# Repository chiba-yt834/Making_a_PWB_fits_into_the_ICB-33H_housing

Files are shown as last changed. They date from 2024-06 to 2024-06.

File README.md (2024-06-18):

## タイトル  
市民ラジオトランシーバー  ICB-33Hの筐体に入る基板  

## はじめに
ICB-33Hの筐体に入る基板を設計したので、情報を公開します。
ICB-33Hは1980年代から1990年代にかけて販売されていたソニー製の市民ラジオのトランシーバーです。  
  
中身を入れ替えることで、新たな市民ラジオのトランシーバーを製作したり、周波数の近い28MHz帯の
アマチュア無線のトランシーバーを製作することができます。
  
本書では設計した基板の外形寸法、スイッチやボリュームなど筐体にとりつく部品の配置、部品の高さ制限の情報などを示します。

## 外形寸法
基板の外形寸法を以下に示します。

[outline_drawing.pdf](./pdf/outline_drawing.pdf)  
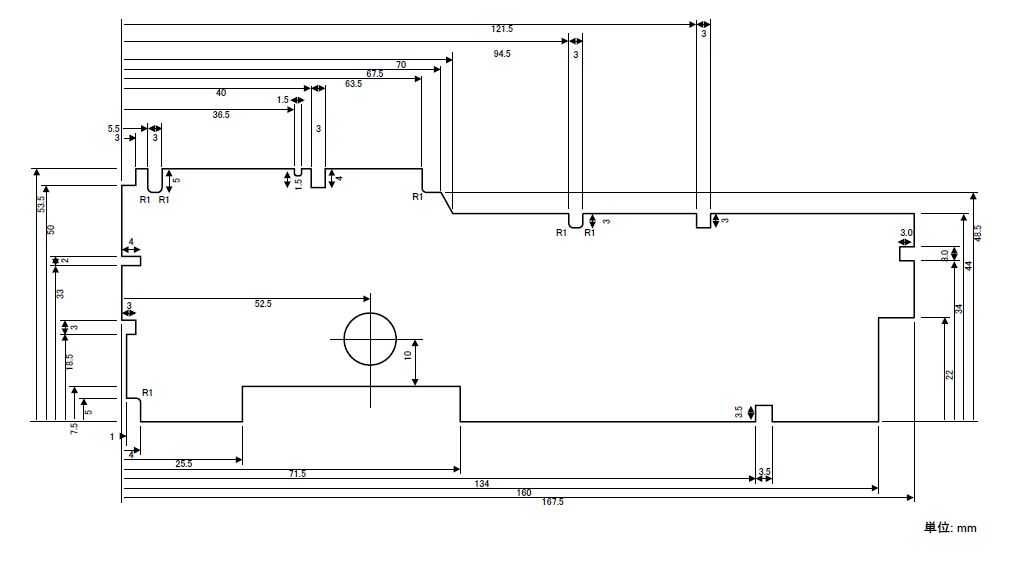
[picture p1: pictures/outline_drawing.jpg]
外形寸法図
  

## ドリル・部品配置
ドリルおよび部品配置の情報を以下に示します。
取り付け穴は全部で4つです。
電池接続パッドは半田面に配置します。それ以外の部品は全て部品面に配置します。

[drill_and_components_layout.pdf](./pdf/drill_and_components_layout.pdf)  
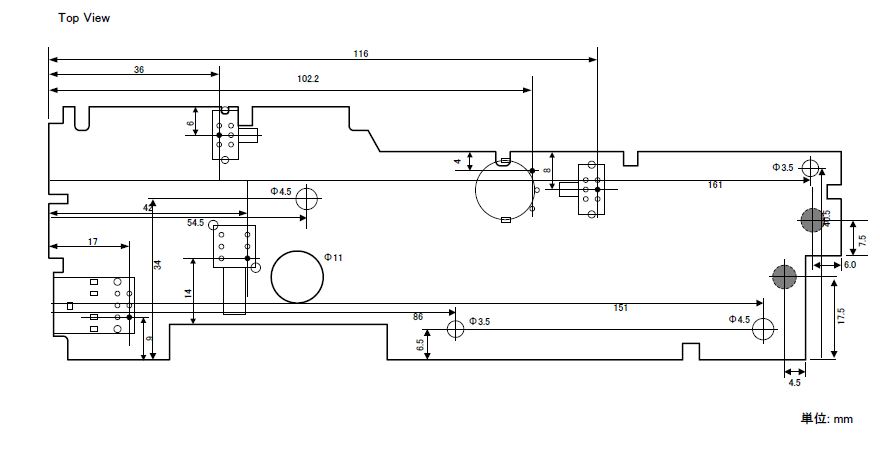
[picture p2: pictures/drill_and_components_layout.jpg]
ドリル・部品配置
  

## 高さ制限
部品面、半田面の高さ制限の情報を以下に示します。
スイッチやボリュームと連動する機構部品や、スピーカーなどと干渉するため、部品の高さ制限や配置禁止領域があります。

* 部品面  
[height_limit(component_side).pdf](./pdf/height_limit(component_side).pdf)  
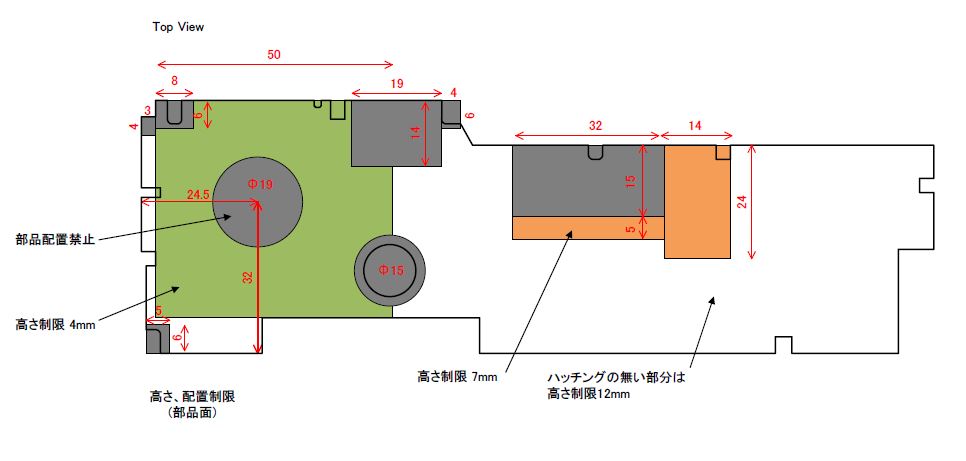
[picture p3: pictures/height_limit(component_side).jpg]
高さ制限_部品面
  
* 半田面  
[height_limit(solder_side).pdf](./pdf/height_limit(solder_side).pdf)  
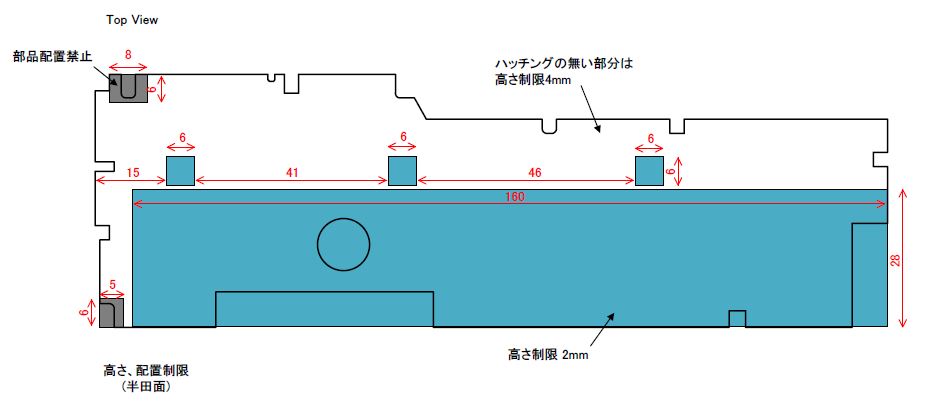
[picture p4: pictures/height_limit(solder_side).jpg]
高さ制限_半田面
  

## 部品
部品取り付け穴の情報を示します。
マイク・イヤホンジャックの部品は位置決め用の樹脂製のボスがありますが、下図には記載していません。ボスを切除してしまうか、
基板に穴を追加する必要があります。

[components.pdf](./pdf/components.pdf)  
* チャネル選択スイッチ  
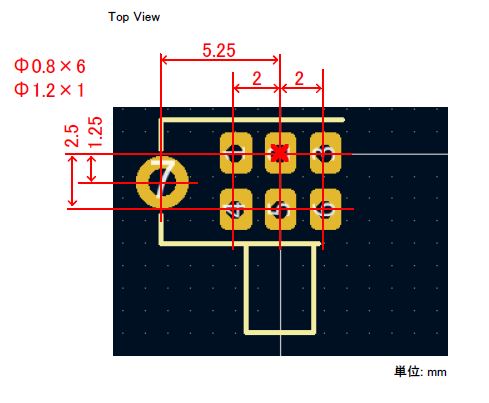
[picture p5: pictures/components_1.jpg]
  
* 電源スイッチ  
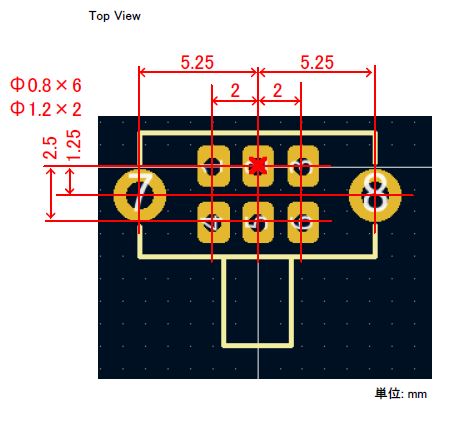
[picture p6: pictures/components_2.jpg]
  
* PTTスイッチ  
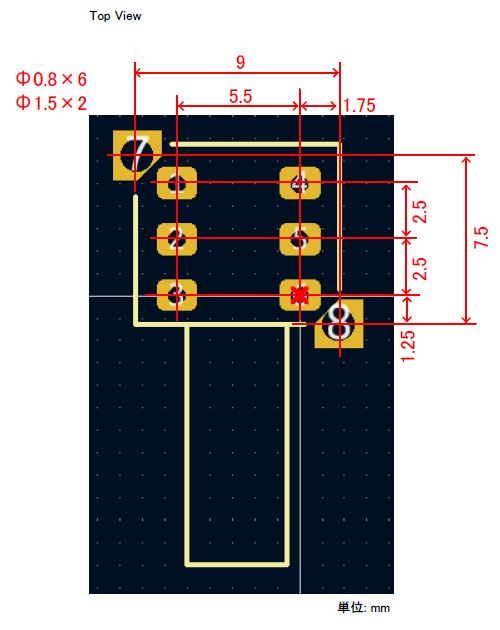
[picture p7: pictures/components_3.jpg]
  
* 音量調節ボリューム  
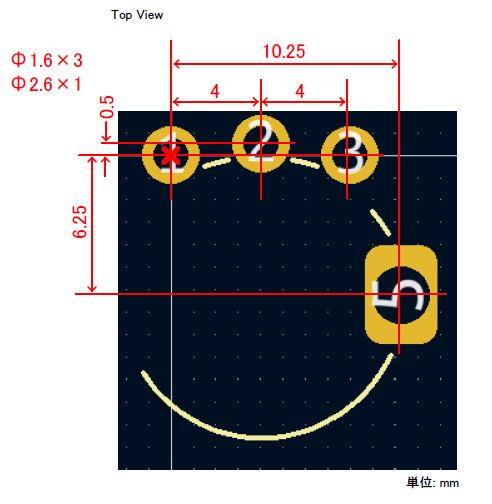
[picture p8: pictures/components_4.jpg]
  
* イヤホン・マイクコネクタ  
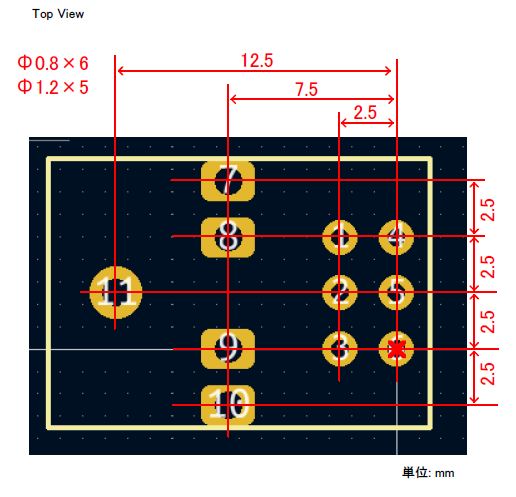
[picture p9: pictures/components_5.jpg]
  
* 電池接続パッド  
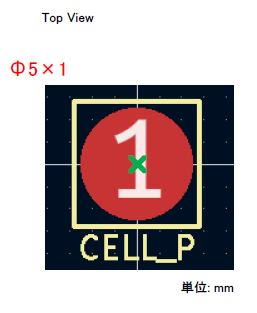
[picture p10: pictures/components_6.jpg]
  

## 実装
基板に部品を実装した様子を示します。
ボリュームの取り付け位置がシビアです。ボリュームの取り付け穴は大きめに設計してあり、遊びを設けてあります。
筐体に基板を組付けてボリュームの取付位置を決めてから、残りの部品を取り付けるとうまくいきます。

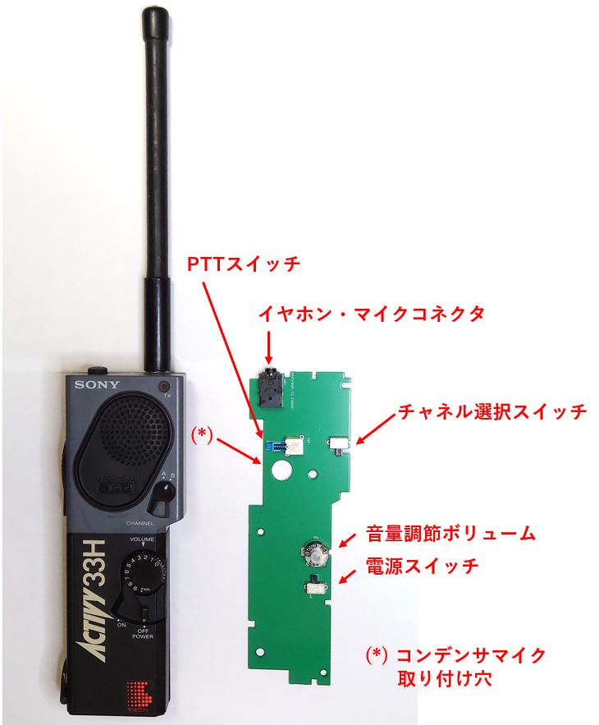
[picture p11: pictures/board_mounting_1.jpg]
実装_部品面
  
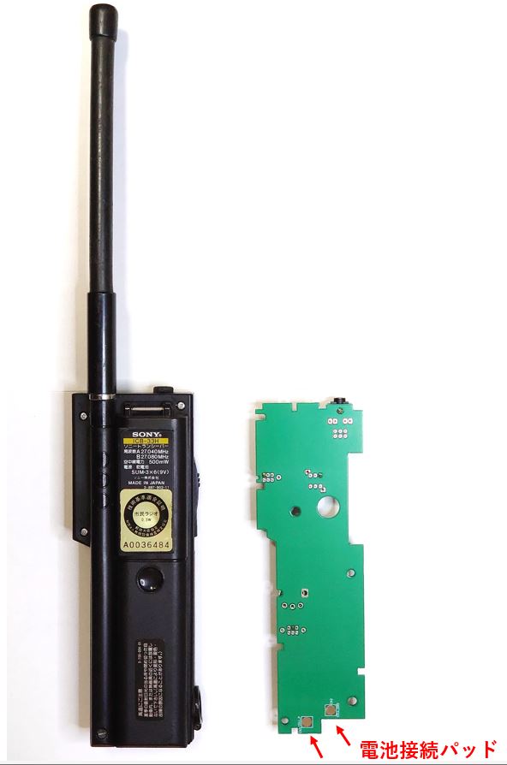
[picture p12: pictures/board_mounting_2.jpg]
実装_半田面
  

## その他 設計情報
上記で示した基板のガーバーデータ、KiCAD データを示します。KiCADはバージョン6.0です。

[gerbers](./gerbers)  
[KiCAD](./KiCAD)  

## 作例
この基板を用いて市民ラジオのトランシーバーを製作し、技適を受けることができました(120mW, 2ch機)。
試験的な交信はできています。
ホイップアンテナは筐体上部にねじ止めされていますが、この部分と基板を電気的にどのように接続するかが難しいところです。

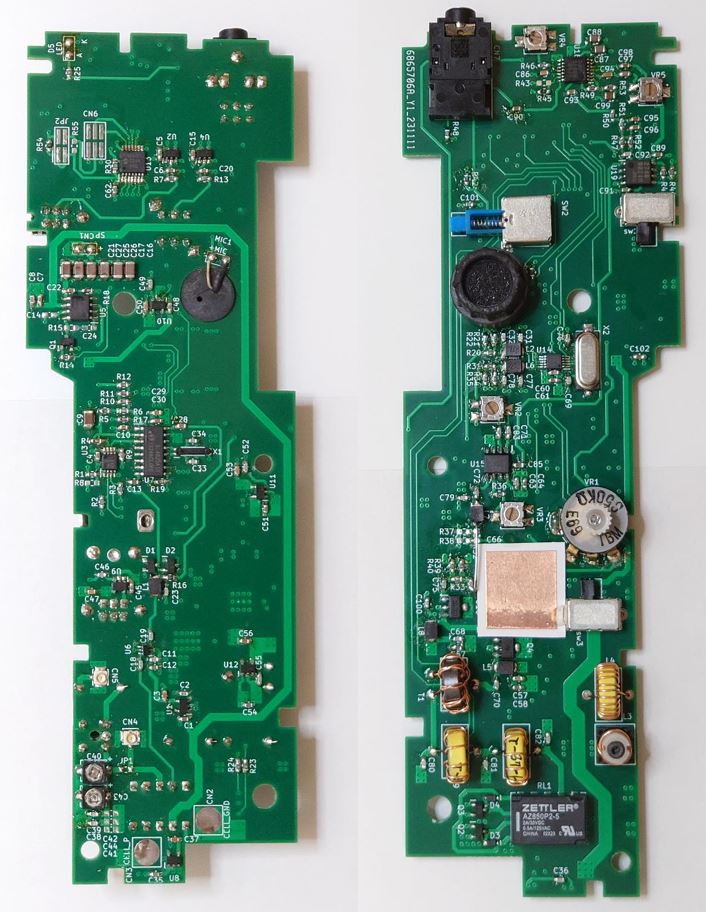
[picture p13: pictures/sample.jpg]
作例_部品面


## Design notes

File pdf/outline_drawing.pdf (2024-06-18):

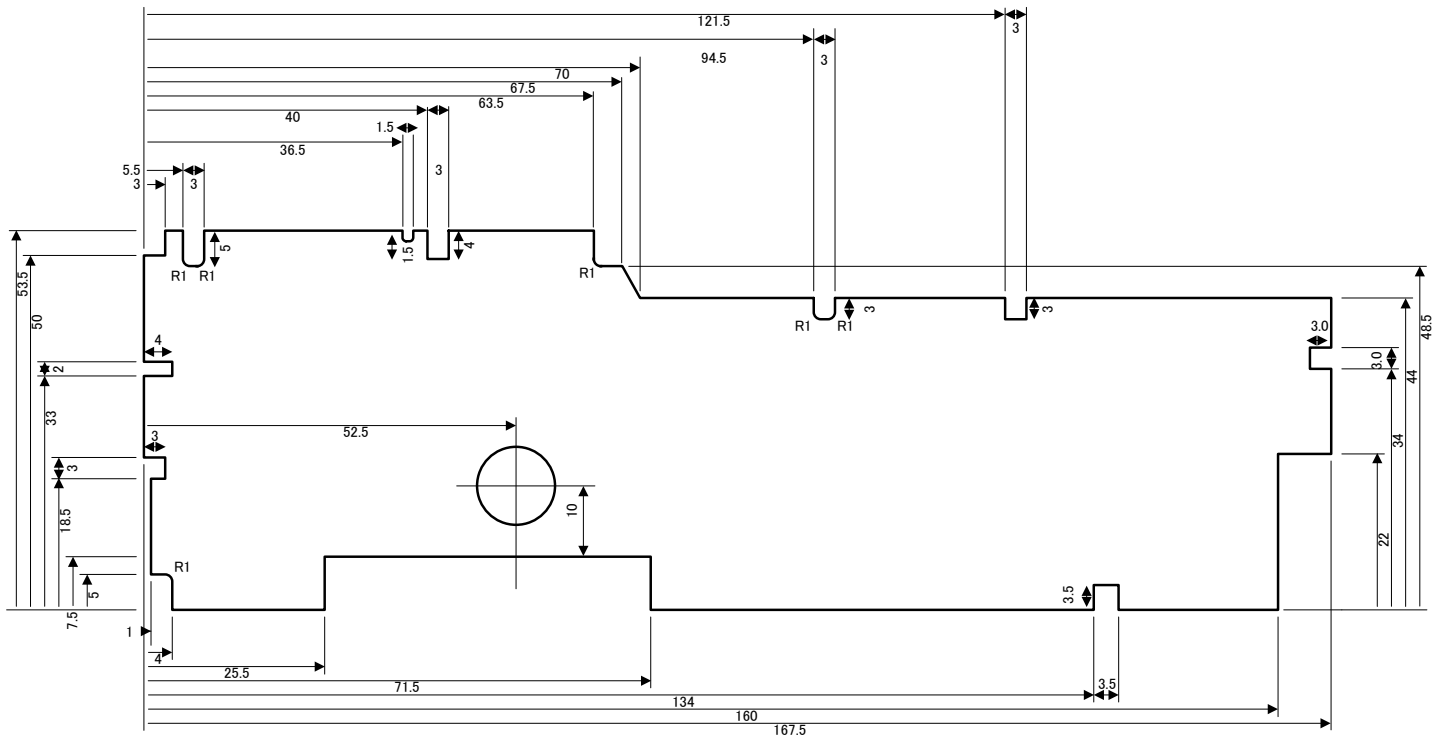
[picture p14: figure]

単

位

:

m

m

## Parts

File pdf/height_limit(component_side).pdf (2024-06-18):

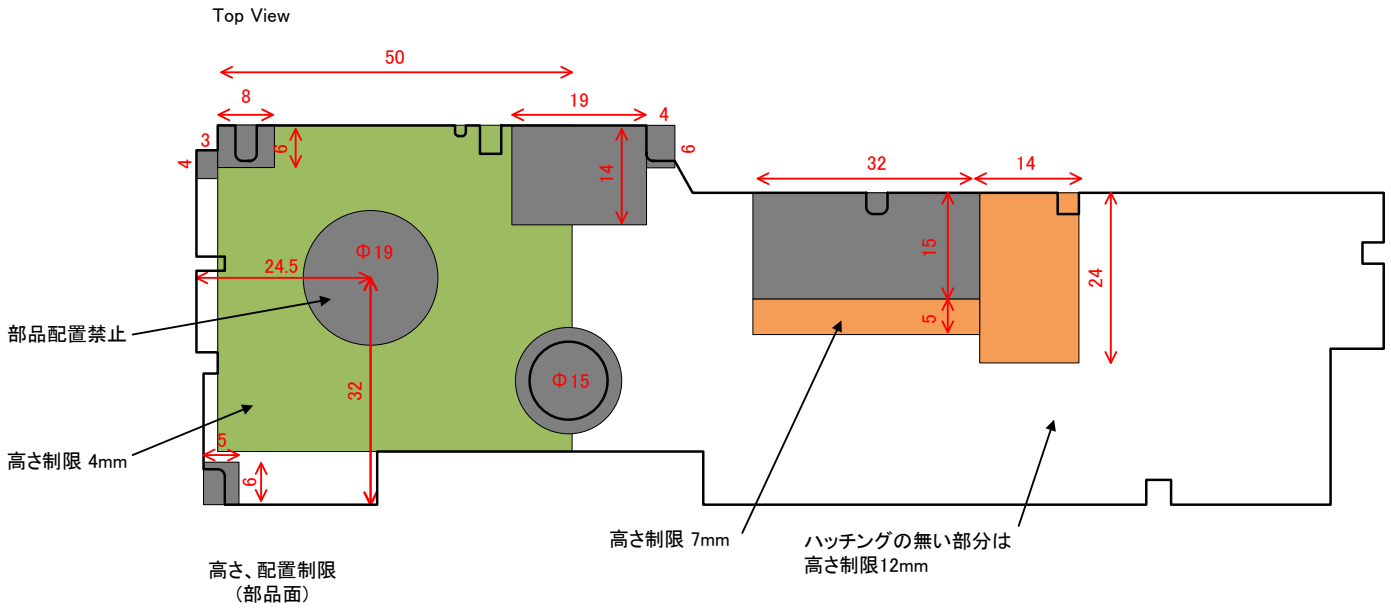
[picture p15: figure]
Top View; 高さ、配置制限 (部品面); 高さ制限 4mm; 部品配置禁止; 高さ制限 7mm; ハッチングの無い部分は; 高さ制限12mm 5

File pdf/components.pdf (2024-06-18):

2 2

2.5
1.2

5

5.25
Φ0.8×6
Φ1.2×1

Top View

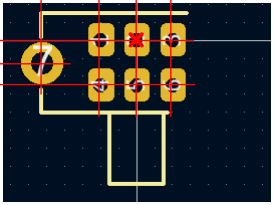
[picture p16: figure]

単位: mm

Top View

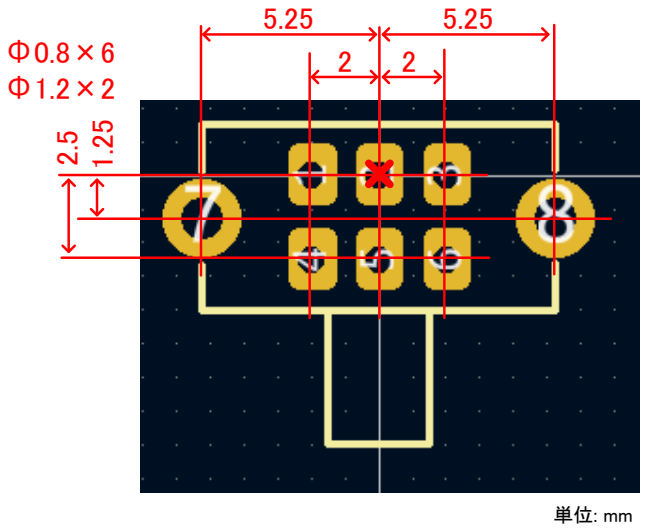
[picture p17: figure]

Top View

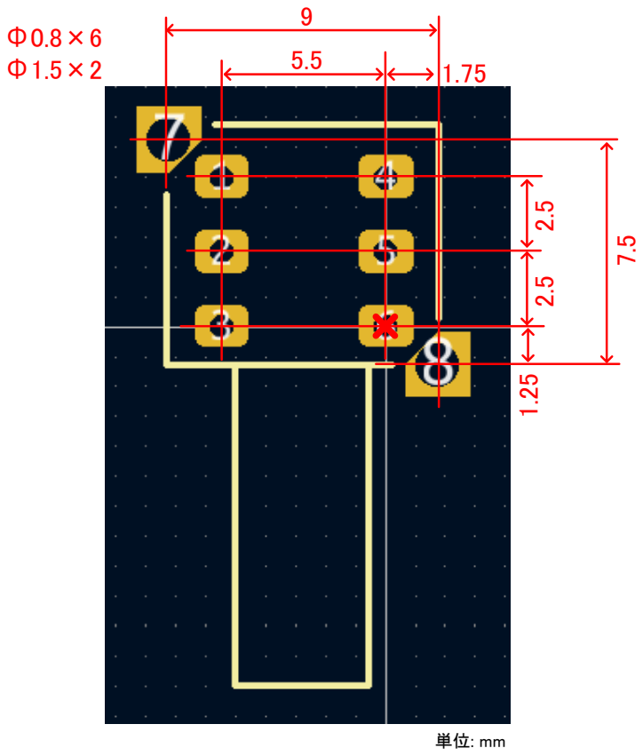
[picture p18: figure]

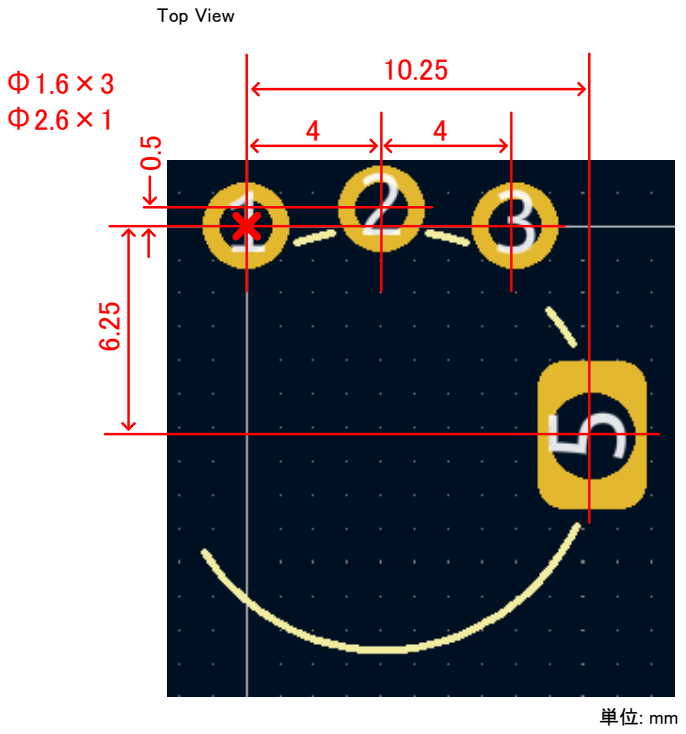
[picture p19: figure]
Top View

Top View

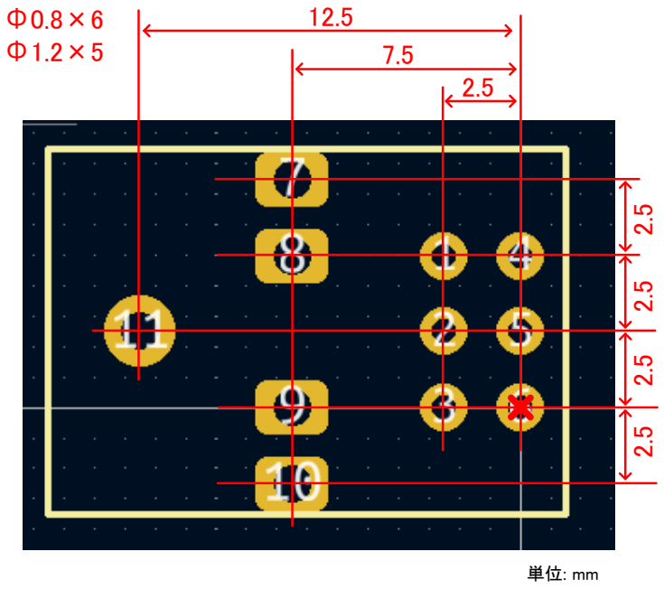
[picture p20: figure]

Φ5×1

Top View

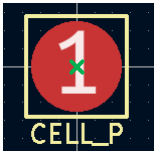
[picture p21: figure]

単位: mm

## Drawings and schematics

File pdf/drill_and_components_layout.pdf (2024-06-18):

T

o

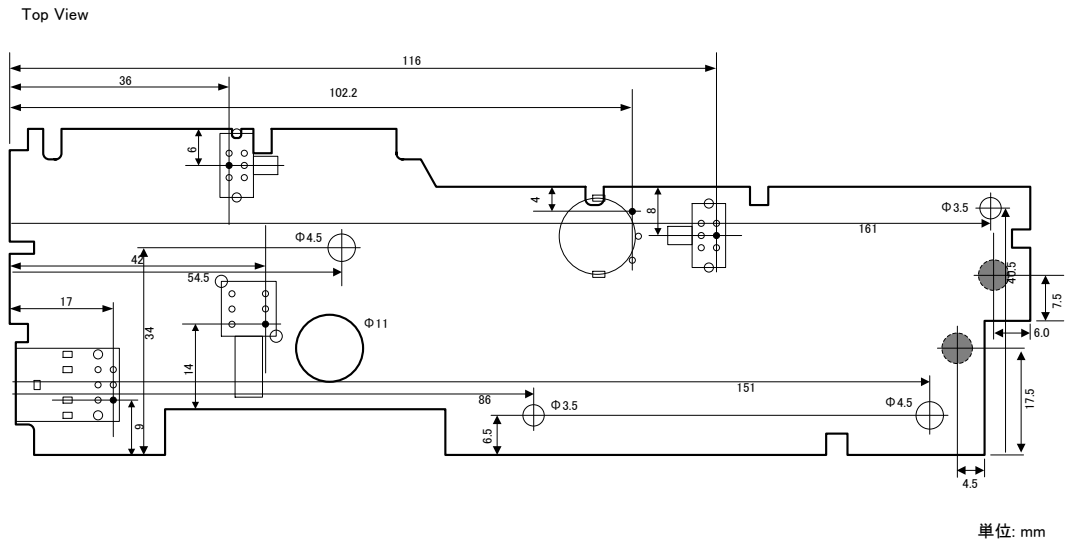
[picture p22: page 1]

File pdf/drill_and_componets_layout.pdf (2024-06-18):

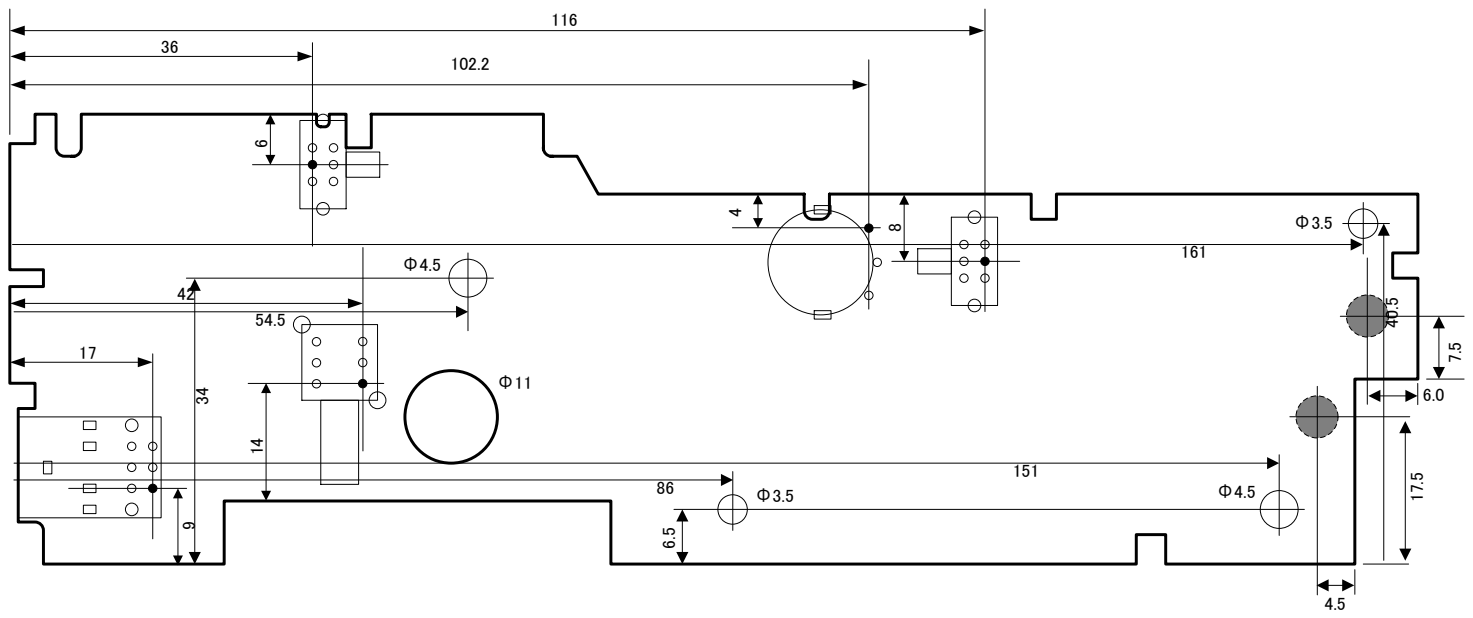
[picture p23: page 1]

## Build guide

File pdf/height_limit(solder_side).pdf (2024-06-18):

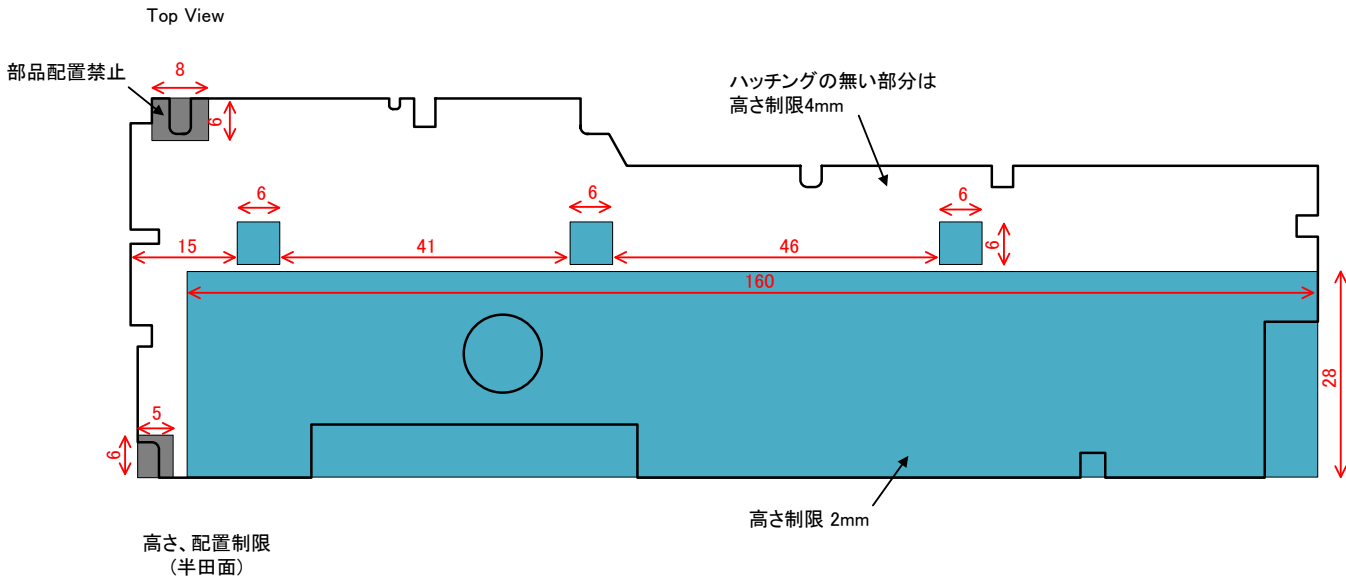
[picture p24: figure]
6 Top View; 高さ、配置制限 (半田面); ハッチングの無い部分は; 高さ制限4mm 6; 高さ制限 2mm; 部品配置禁止
